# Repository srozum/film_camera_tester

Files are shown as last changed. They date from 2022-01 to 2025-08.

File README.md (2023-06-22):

# Film Camera Tester

The idea of using Arduino for measuring camera shutter timings is not new. What I've tried to do here, is to make a modular system with a set of features normally offered in professional testers, at the same time to keep its design simple and available to reproduce using off-the-shelf components.

Usually, time counting and/or light integration methods are used to test cameras. For the time counting method, you need a light sensor, a time counter, and a simple light source. With such setup you can measure exposure time(s) provided by a shutter, curtains travel speed of a focal plane shutter, flash sync contact delays, etc.
For the second method, you'll need a photosensor able to measure the amount of light and a calibrated light source. With such setup, you'll be able to measure actual exposure produced by a system "camera+lens", light meter accuracy, operation of auto-exposure cameras, etc.

This tester allows you to perform both time-based and light integration tests and calibrations of film cameras.

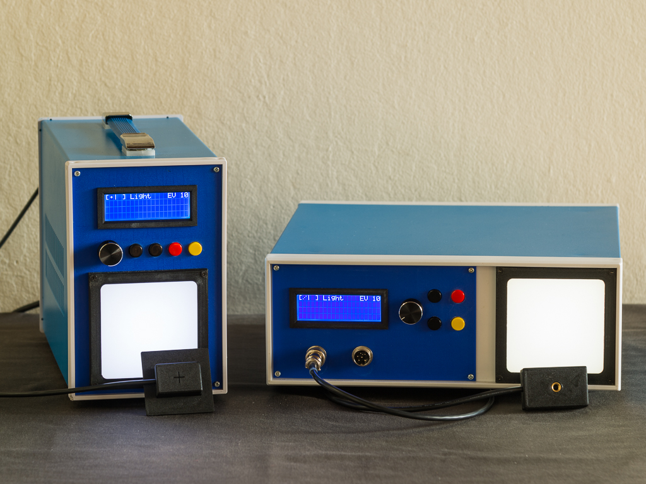
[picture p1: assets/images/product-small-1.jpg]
Film Camera Tester


### Features and characteristics

- Measures actual exposure at the film plane, which allows to test fully automatic, aperture or shutter priority cameras.
  - Accuracy ±0.05EV within 6-14EV range, although full range 5-17EV of a Light Unit can be used for testing.
  - Resolution 0.01EV
- Measures exposure time at the center of a frame of simple (leaf) and focal plane shutters of 35mm and Medium Format (6x6 or 6x45 using adapter) cameras.
  - In v2.7 only: For leaf shutters of size #00 and #0 calculates estimated effective speed according to efficiency curve.
- Measures timings of focal plane shutters with curtains traveling vertically or horizontally.
  - Results can be represented in a few different ways to help you detect different flaws in a shutter operation, such as curtains capping or tapering, uneven travel speed, etc.
  - Automatically re-calculates curtains travel time according to selected frame width or height.
- Measures delays between flash contact and shutter opening.
  - Automatically identifies X, M, or FP modes.
- Takes a series of measurements, and calculates average stats.
  - Number of tests in series can be selected in the Settings menu between 3, 5, 10, or 20.
- Allows to measure efficiency thus effective speed of a leaf shutters from size #00 and bigger.
- Automatically detects the type of connected Sensors, and notifies you if wrong sensor is connected for a specific Mode.
- Automatically detects target speed used to calculate the error.
  - Target speed can be set to "Auto" or pre-set from a list of standard speeds.
  - You also can select between two sets of standard speeds (Old style like 1/50 or New style like 1/60), depending on the type of shutter you are testing.
- Range of measured speeds from 1s to 1/8000
- Accuracy 10µs (measured in the pre-set environment, using a signal generator and specialized light source)
  - Accuracy may vary during real-life measurements with different light sources and cameras.
- Allows to check accuracy and calibrate light meters and light meters built into a cameras.
  - Light Source brightness is adjustable within 5-17EV range
  - Light Source can be switched between K12.5 and K14.03 light levels

More information on [Wiki](https://github.com/srozum/film_camera_tester/wiki).

### Buy or DIY

Since the SRT-2 Kits (assembled or not assembled), which were offered on my Tindie store, are all sold and will not be produced anymore, your only option is to make it yourself.

In '/assets' folder you can find all schematics, PCB production files, and STLs for 3D printed parts necessary to build the Tester. I recommend you carefully read Wiki pages first, explore schematics and product photos before you start ordering the parts.

### Big Thanks to

Big thanks to everyone who supported the project from the beginning.

Similar projects that helped me to start my own

 - [https://github.com/cameradactyl/Shutter-Timer](https://github.com/cameradactyl/Shutter-Timer)
 - [https://github.com/ianonahillroad/CameraShutterTimer](https://github.com/ianonahillroad/CameraShutterTimer)
 - [https://github.com/c-s-1/shutter-tester](https://github.com/c-s-1/shutter-tester)
 - [https://github.com/sokol07/LaserShutterTester](https://github.com/sokol07/LaserShutterTester)

---
This work is licensed under a [Creative Commons Attribution-ShareAlike 4.0 International License][cc-by-sa].

[][cc-by-sa]

[cc-by-sa]: http://creativecommons.org/licenses/by-sa/4.0/
[cc-by-sa-image]: https://licensebuttons.net/l/by-sa/4.0/88x31.png

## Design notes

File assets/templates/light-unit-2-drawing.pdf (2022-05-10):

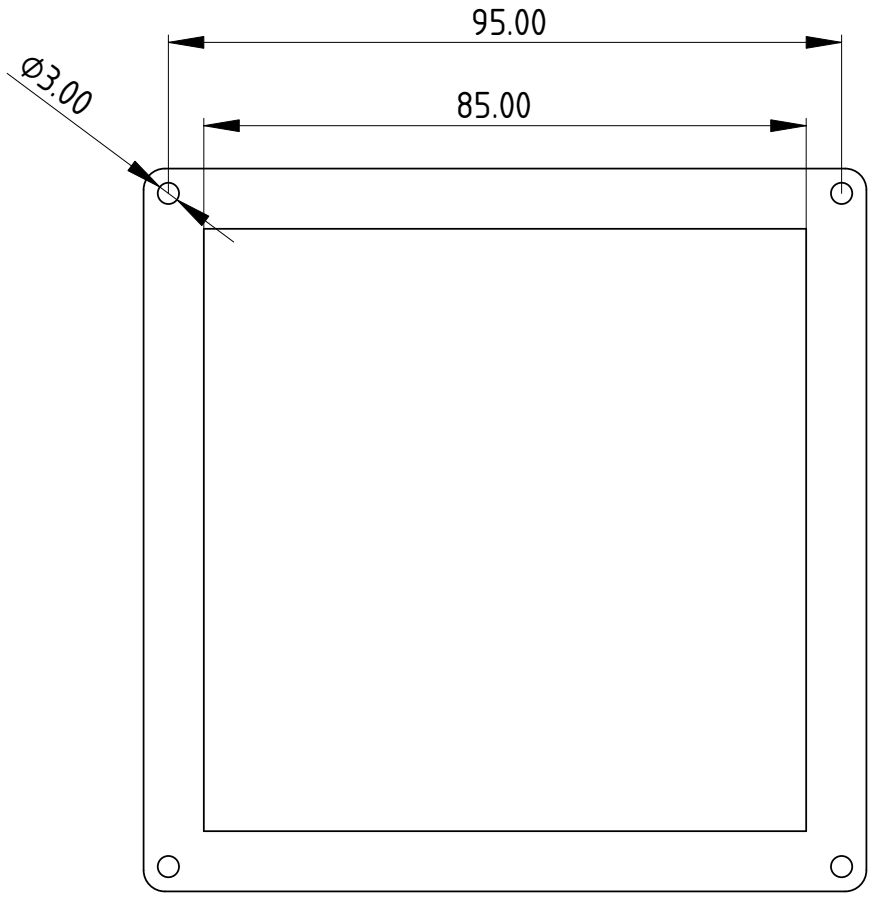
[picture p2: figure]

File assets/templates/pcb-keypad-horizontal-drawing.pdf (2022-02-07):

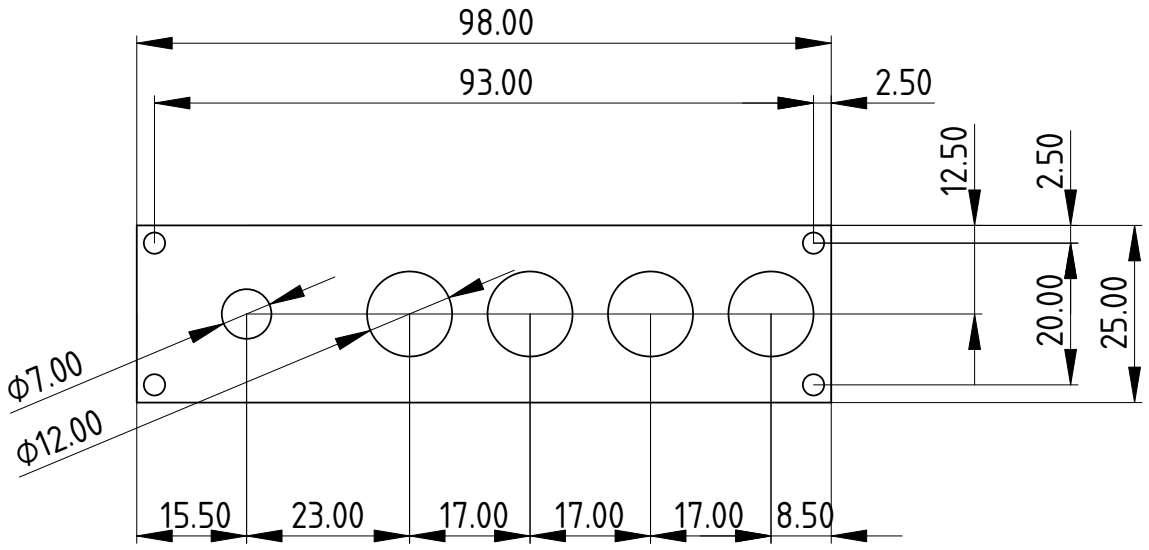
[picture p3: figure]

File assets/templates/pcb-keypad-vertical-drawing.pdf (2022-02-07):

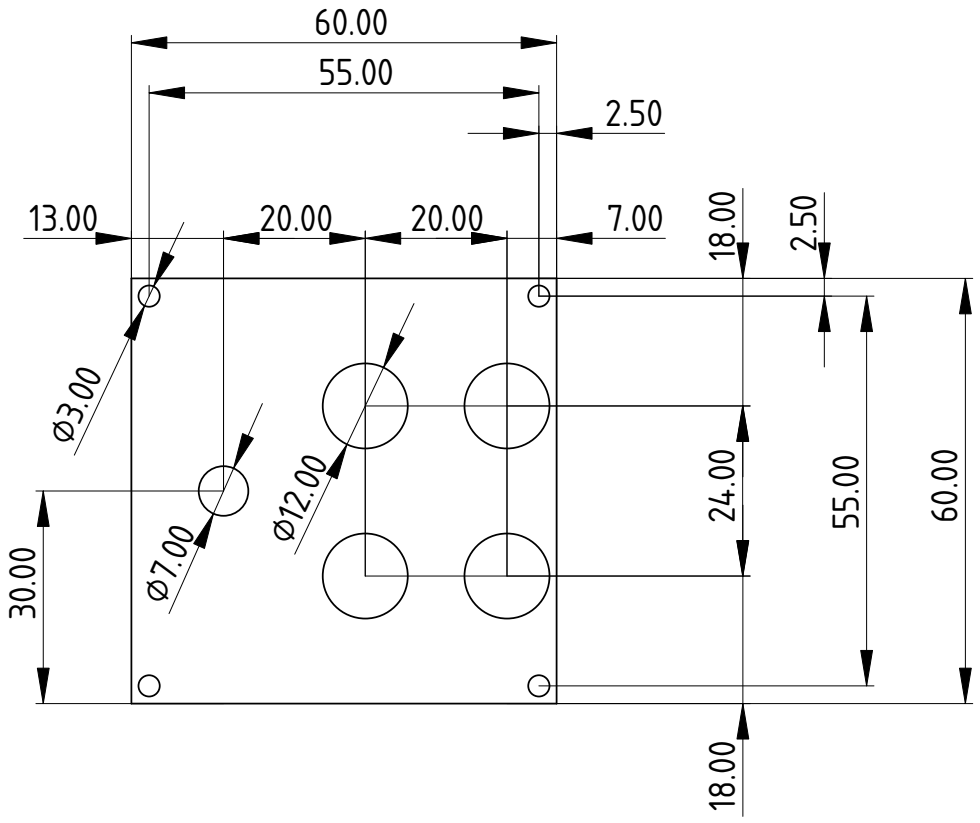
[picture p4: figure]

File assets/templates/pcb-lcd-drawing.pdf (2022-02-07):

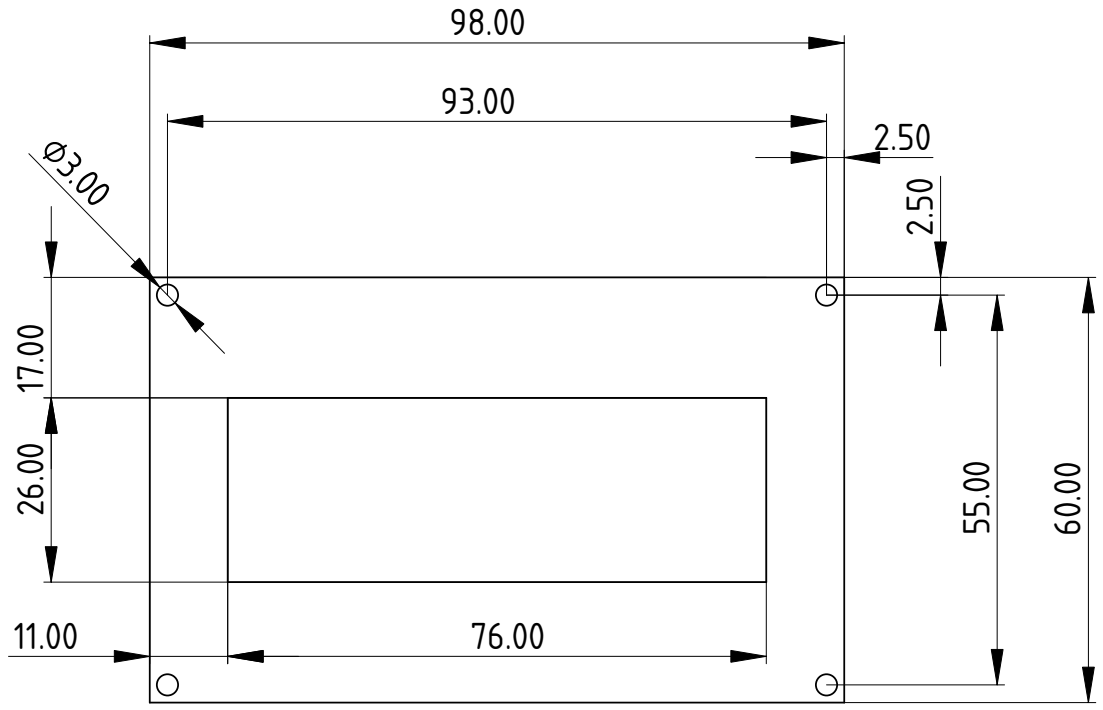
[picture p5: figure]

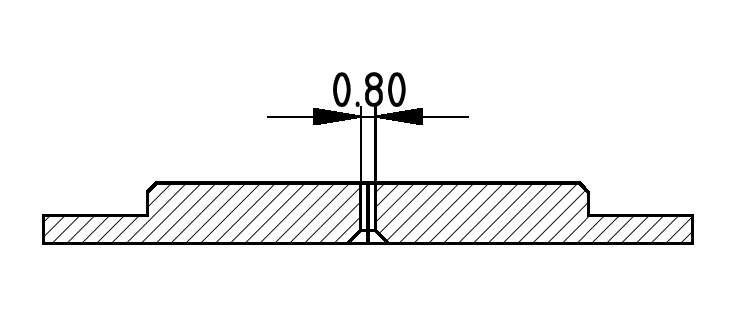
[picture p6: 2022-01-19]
assets/schematics/sensor-face-plate.png

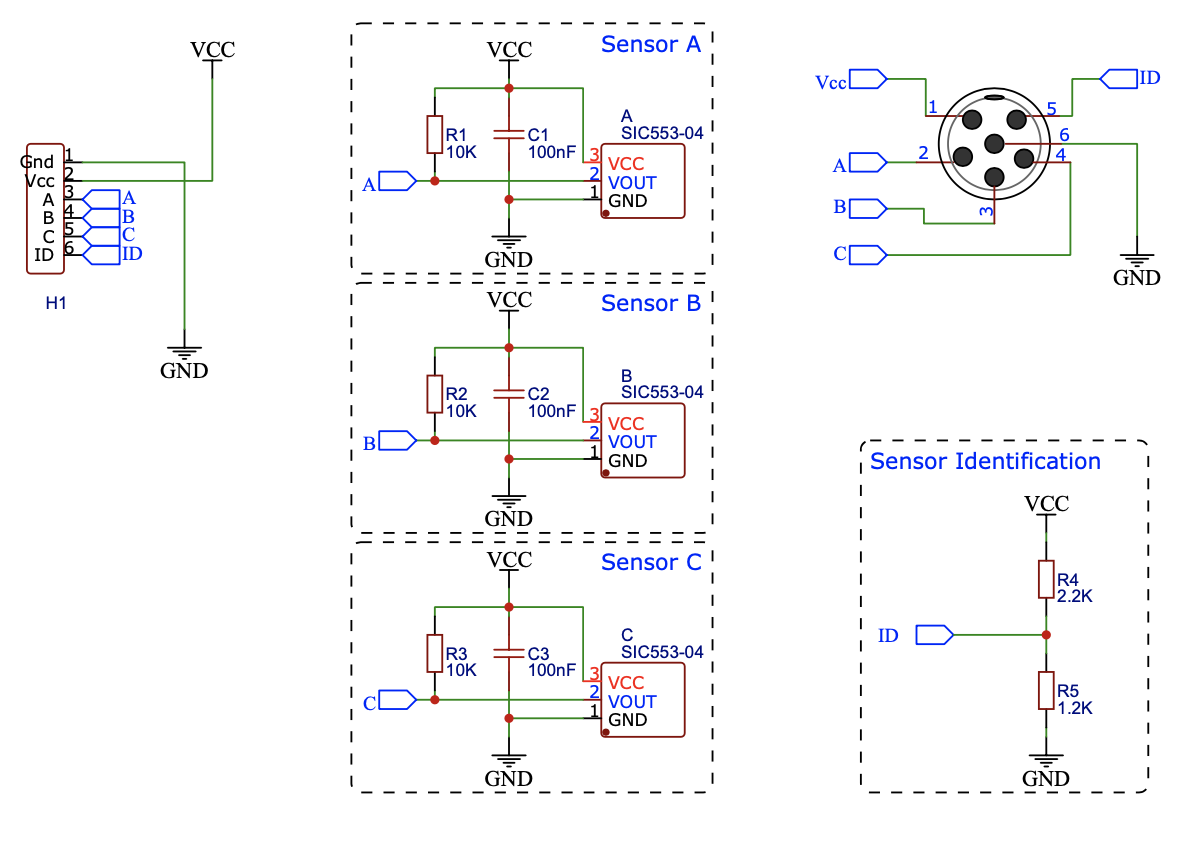
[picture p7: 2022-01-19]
assets/schematics/sensor1-v2.png

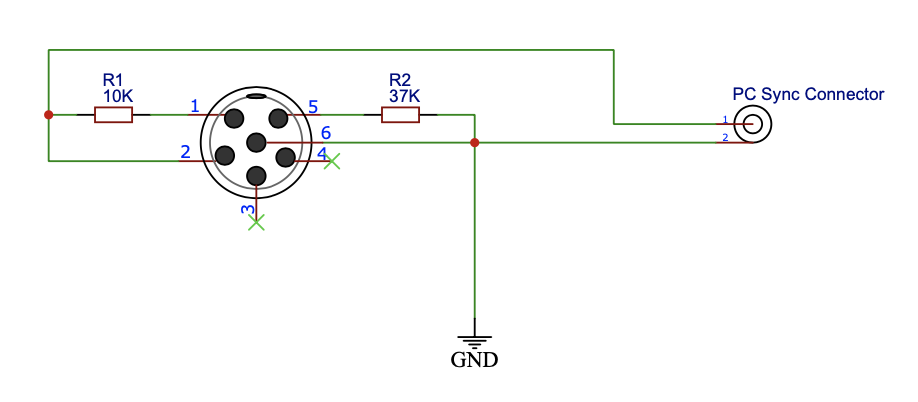
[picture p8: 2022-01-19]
assets/schematics/sensor7.png

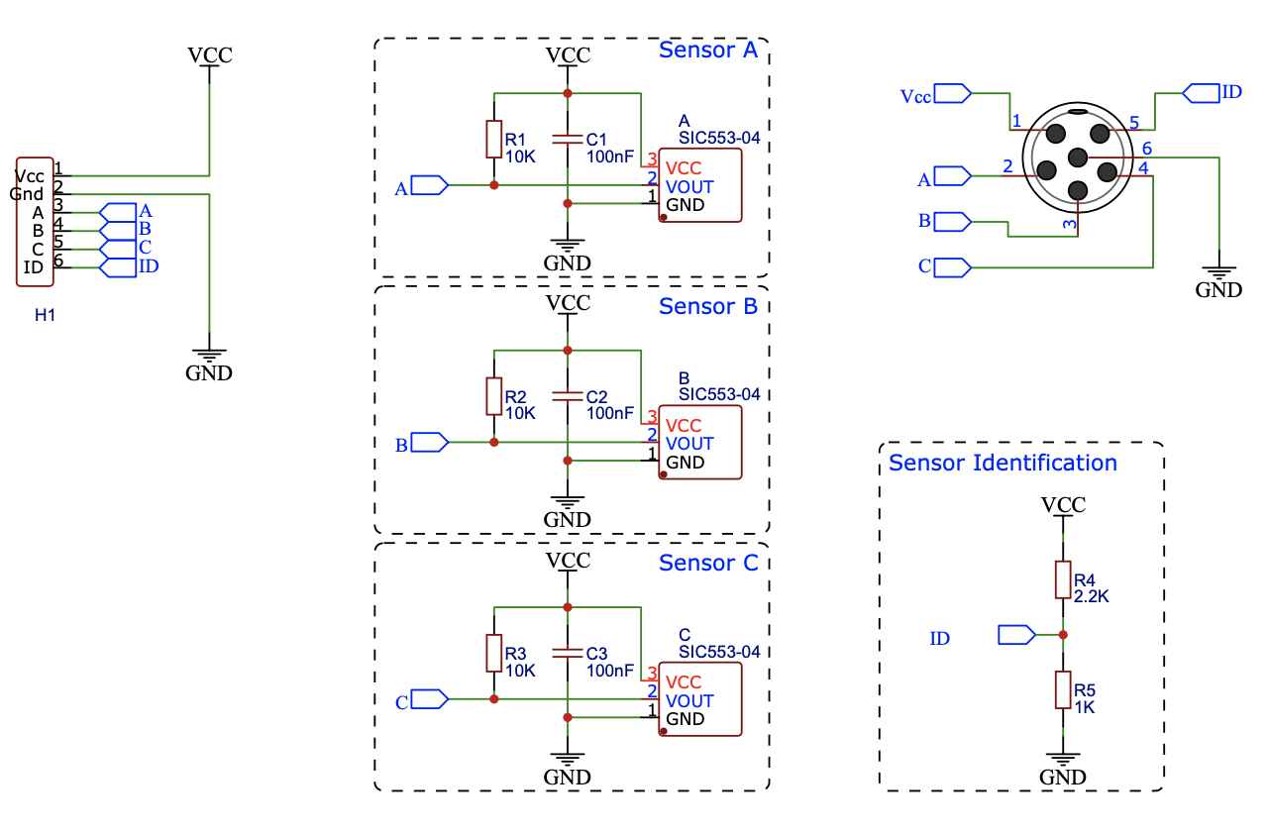
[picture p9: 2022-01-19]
assets/schematics/sensor1-v1.png

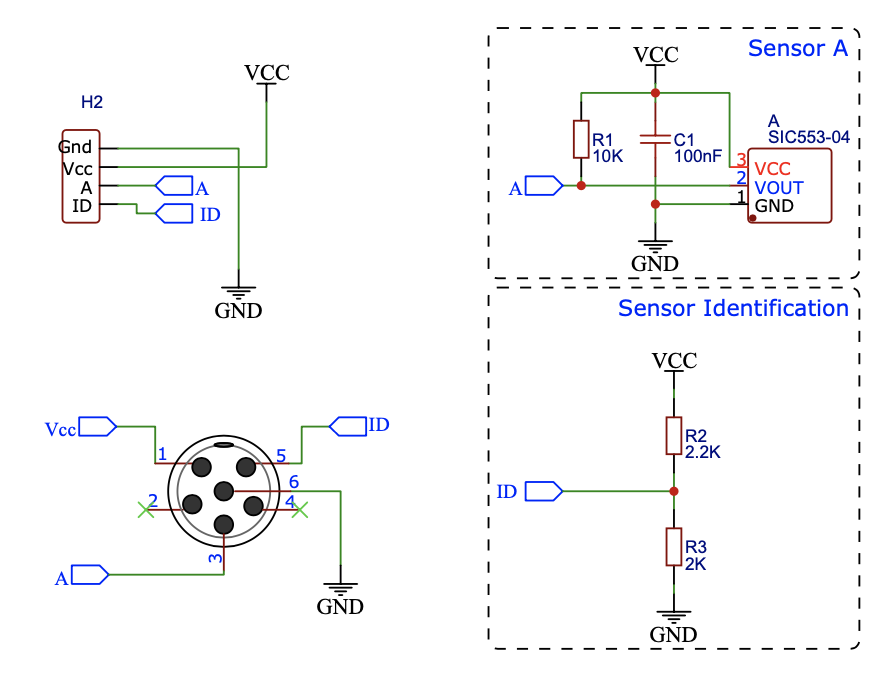
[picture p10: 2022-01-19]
assets/schematics/sensor2-v1.png

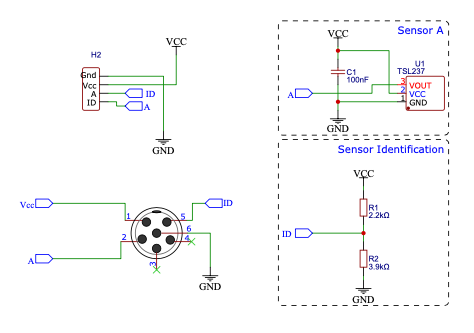
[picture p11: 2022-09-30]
assets/schematics/sensor6-v1.png

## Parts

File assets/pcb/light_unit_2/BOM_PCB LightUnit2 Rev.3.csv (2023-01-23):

ID | Name | Designator | Footprint | Quantity | Manufacturer Part | Manufacturer | Supplier | Supplier Part | Price
1 | 220uF | C1 | CAP-TH_BD10.0-P5.00-D1.0-FD | 1 | 220uF 50V 10*13 | ValuePro | LCSC | C45105 | 0.068
2 | 470uF | C2 | CAP-TH_BD10.0-P5.00-D1.0-FD | 1 | 25YXJ470MFFC10X12.5 | Rubycon | LCSC | C368591 | 0.138
3 | B2B-PH-K-S(LF)(SN) | LED,FAN | CONN-TH_B2B-PH-K-S | 2 | B2B-PH-K-S(LF)(SN) | JST | LCSC | C131337 | 0.036
4 | 2N2222A | Q1 | TO-92-3_L4.9-W3.7-P1.27-L | 1 | 2N2222 | SEMTECH | LCSC | C118536 | 0.021
5 | 1N4001-E3/73 | D1 | DO-41_BD2.4-L4.7-P8.70-D0.9-RD | 1 | 1N4001-E3/73 | VISHAY | LCSC | C145491 | 0.175
6 | HDR-M-2.54_1x6 | J1 | HDR-M-2.54_1X6 | 1 |  |  | LCSC | C190819 | 0.033
7 | LD24AJTA | U1 | LD24AJTA | 1
8 | 2K | R1 | RES-TH_BD2.2-L6.5-P10.50-D0.6 | 1 | MFR0W4F2001A50 | UniOhm | LCSC | C58593 | 0.01
9 | 2.2K | R2 | RES-TH_BD2.2-L6.5-P10.50-D0.6 | 1 | MFR0W4F2201A50 | UniOhm | LCSC | C58595 | 0.01
10 | B2B-XH-A (LF)(SN) | 12V | CONN-TH_B2B-XH-A-LF-SN | 1 | - | JST Sales America | LCSC | C158012 | 0.031
11 | 4.7K | R3,R4 | RES-TH_BD2.2-L6.5-P10.50-D0.6 | 2 | CFR0W4J0472A50 | UniOhm | LCSC | C61297 | 0.008

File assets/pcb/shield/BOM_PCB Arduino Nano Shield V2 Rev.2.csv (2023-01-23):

ID | Name | Designator | Footprint | Quantity | Manufacturer Part | Manufacturer | Supplier | Supplier Part | Price
1 | B3B-XH-A(LF)(SN) | U8 | CONN-TH_3P-P2.50_B3B-XH-A-LF-SN | 1 | B3B-XH-A(LF)(SN) | JST Sales America | LCSC | C144394 | 0.042
2 | LCD | LCD | HDR-M-2.54_1X4 | 1 |  |  | LCSC | C124378 | 0.028
3 | 24V | P1 | CONN-TH_WJ126V-5.0-2P | 1 | WJ126V-5.0-2P | ReliaPro | LCSC | C8404 | 0.065
4 | 220uF | C1,C2 | CAP-TH_BD10.0-P5.00-D1.0-FD | 2 | 220uF 50V 10*13 | ValuePro | LCSC | C45105 | 0.056
5 | Keypad | CN1 | CONN-TH_B9B-XH-A-LF-SN | 1 | - | JST Sales America | LCSC | C157966 | 0.124
6 | 10K | R1,R2 | RES-TH_BD2.5-L6.5-P10.50-D0.6 | 2 | MFR0W4F1002A50 | UniOhm | LCSC | C57436 | 0.008
7 | Light Unit | U2 | CONN-TH_6P-P2.50_B6B-XH-A-LF-SN | 1 | B6B-XH-A(LF)(SN) | JST Sales America | LCSC | C144397 | 0.072
8 | Socket A | U3 | CONN-TH_6P-P2.50_B6B-XH-A-LF-SN | 1 | B6B-XH-A(LF)(SN) | JST Sales America | LCSC | C144397 | 0.072
9 | Socket B | U4 | CONN-TH_6P-P2.50_B6B-XH-A-LF-SN | 1 | B6B-XH-A(LF)(SN) | JST Sales America | LCSC | C144397 | 0.072
10 | ArduinoNanoATmega328P | U9 | ARDUINONANO | 1
11 | active buzzer 2300Hz | BUZ1 | ACTIVE BUZZER 2300HZ | 1 | active buzzer 2300Hz

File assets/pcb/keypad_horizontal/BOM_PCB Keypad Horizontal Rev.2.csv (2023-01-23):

ID | Name | Designator | Footprint | Quantity | Manufacturer Part | Manufacturer | Supplier | Supplier Part | Price
1 | 100nF | C1,C2,C3,C4 | C0603 | 4 | CC0603KRX7R9BB104 | YAGEO | LCSC | C14663 | 0.003
2 | 10nF | C5,C6,C7 | C0603 | 3 | 0603B103K500NT | FH | LCSC | C57112 | 0.003
3 | 10K | R1,R3,R5,R6,R7,R9,R11,R12,R13,R14 | R0603 | 10 | 0603WAF1002T5E | UniOhm | LCSC | C25804 | 0.001
4 | 220 | R2,R4,R8,R10 | R0603 | 4 | 0603WAF2200T5E | UniOhm | LCSC | C22962 | 0.001

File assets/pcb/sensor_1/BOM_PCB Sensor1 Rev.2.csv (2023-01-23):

ID | Name | Designator | Footprint | Quantity | Manufacturer Part | Manufacturer | Supplier | Supplier Part | Price
1 | SIC553-04 | A,B,C | OPTO-TH_SIC553-04 | 3 | SIC553-04 | Kodenshi AUK | LCSC | C188181 | 0.566
2 | 100nF | C1,C2,C3 | C0603 | 3 | CC0603KRX7R9BB104 | YAGEO | LCSC | C14663 | 0.003
3 | 10K | R1,R2,R3 | R0603 | 3 | 0603WAF1002T5E | UniOhm | LCSC | C25804 | 0.001
4 | 2.2K | R4 | R0603 | 1 | 0603WAF2201T5E | UniOhm | LCSC | C4190 | 0.001
5 | 1.2K | R5 | R0603 | 1 | 0603WAF1201T5E | UniOhm | LCSC | C22765 | 0.001

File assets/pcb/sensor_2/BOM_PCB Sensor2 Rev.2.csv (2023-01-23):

ID | Name | Designator | Footprint | Quantity | Manufacturer Part | Manufacturer | Supplier | Supplier Part | Price
1 | SIC553-04 | A | OPTO-TH_SIC553-04 | 1 | SIC553-04 | Kodenshi AUK | LCSC | C188181 | 0.566
2 | 100nF | C1 | C0603 | 1 | CC0603KRX7R9BB104 | YAGEO | LCSC | C14663 | 0.003
3 | 10K | R1 | R0603 | 1 | 0603WAF1002T5E | UniOhm | LCSC | C25804 | 0.001
4 | 2.2K | R2 | R0603 | 1 | 0603WAF2201T5E | UniOhm | LCSC | C4190 | 0.001
5 | 2K | R3 | R0603 | 1 | 0603WAF2001T5E | UniOhm | LCSC | C22975 | 0.001

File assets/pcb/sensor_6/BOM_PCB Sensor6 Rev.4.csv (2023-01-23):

ID | Name | Designator | Footprint | Quantity | Manufacturer Part | Manufacturer | Supplier | Supplier Part | Price
1 | TSL237 | U1 | OPTO-TH_SIC553-04 | 1 | SIC553-04 | Kodenshi AUK | LCSC | C188181 | 0.106
2 | 100nF | C1 | C0805 | 1 | CL21B104KCFNNNE | SAMSUNG | LCSC | C28233 | 0.001
3 | 2.2kΩ | R1 | R0805 | 1 | 0805W8F2201T5E | UniOhm | LCSC | C17520
4 | 3.9kΩ | R2 | R0805 | 1 | 0805W8F3901T5E | UniOhm | LCSC | C17614

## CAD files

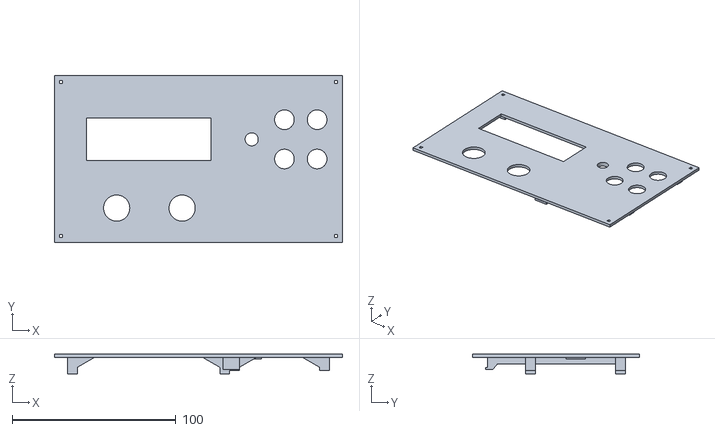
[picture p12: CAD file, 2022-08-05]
assets/stl/front-panel/horizontal_panel.stl
176.0 x 102.0 x 12.0

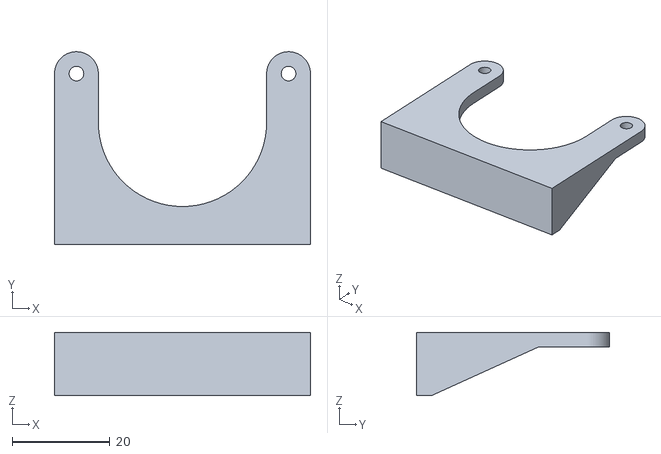
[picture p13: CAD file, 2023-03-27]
assets/stl/light-unit/support-stand.stl
52.5 x 39.5 x 13.0

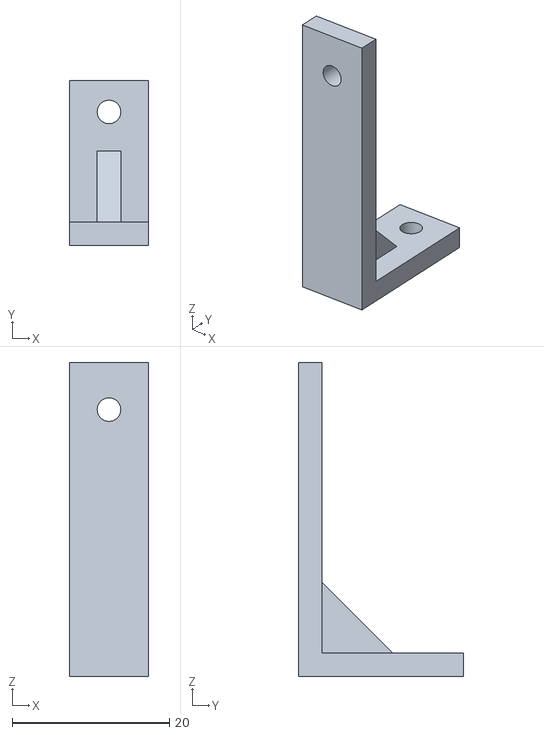
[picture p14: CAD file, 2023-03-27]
assets/stl/pcb-angle-mount.stl
10.0 x 21.0 x 40.0

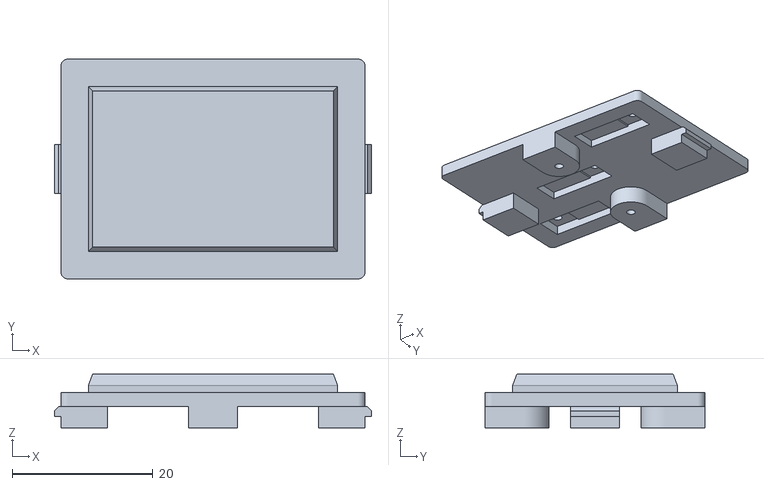
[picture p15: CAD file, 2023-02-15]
assets/stl/sensor-6/face_plate.stl
45.0 x 31.2 x 7.60

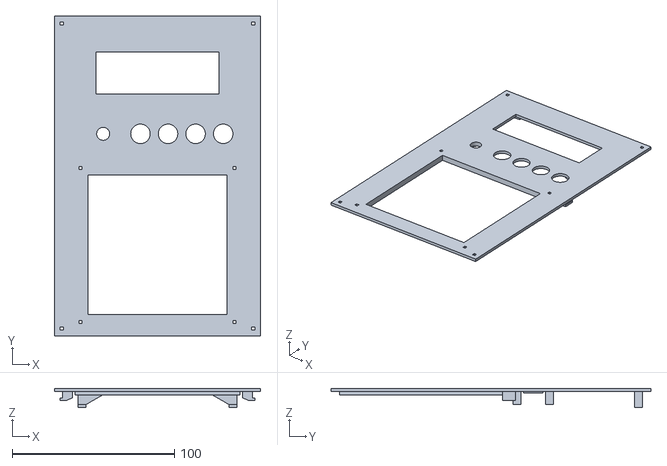
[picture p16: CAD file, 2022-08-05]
assets/stl/front-panel/vertical_panel.stl
127.0 x 197.0 x 12.0

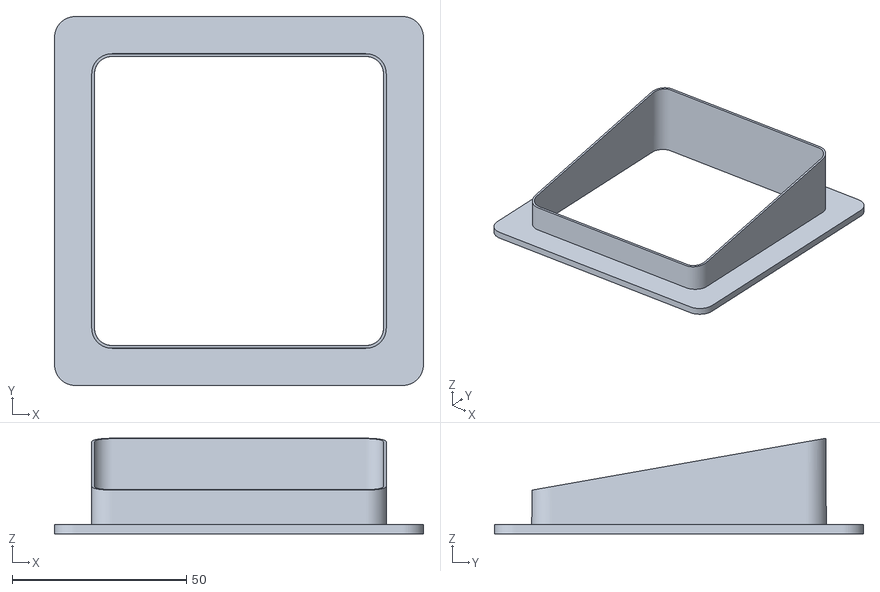
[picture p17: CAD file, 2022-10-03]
assets/stl/light-unit/flexible-hood.stl
106.0 x 106.0 x 27.5

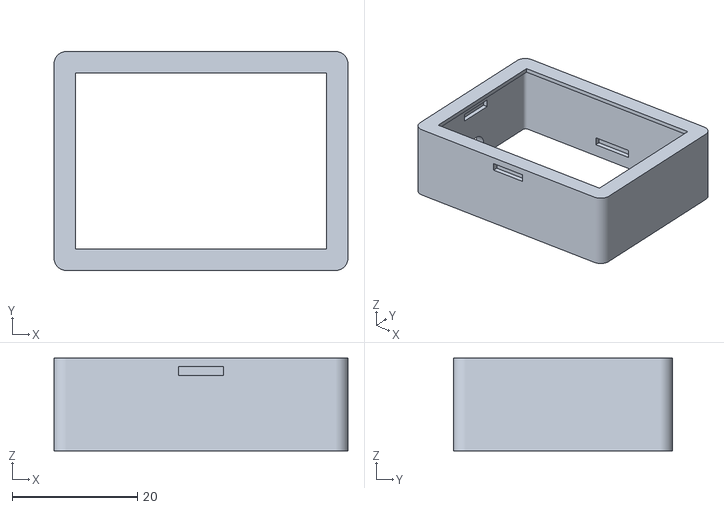
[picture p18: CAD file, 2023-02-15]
assets/stl/sensor-6/body.stl
47.0 x 35.0 x 14.8

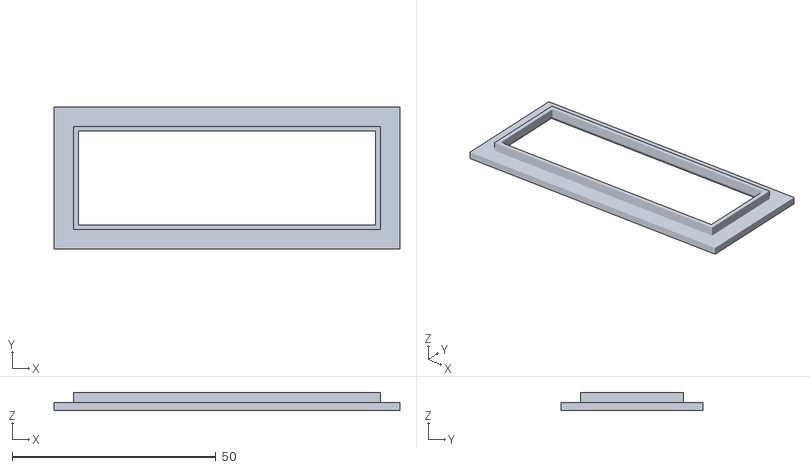
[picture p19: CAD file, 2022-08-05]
assets/stl/front-panel/lcd_besel.stl
85.0 x 35.0 x 4.50

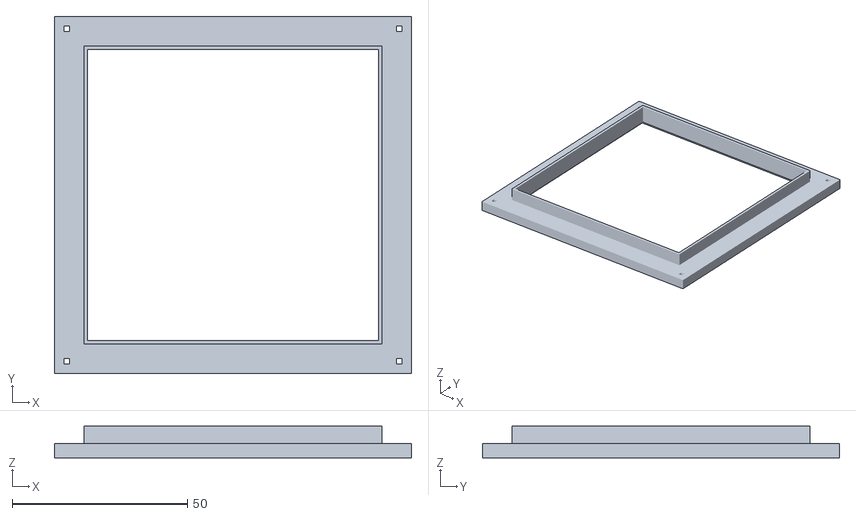
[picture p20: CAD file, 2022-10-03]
assets/stl/light-unit/reflector-mount.stl
102.0 x 102.0 x 9.00

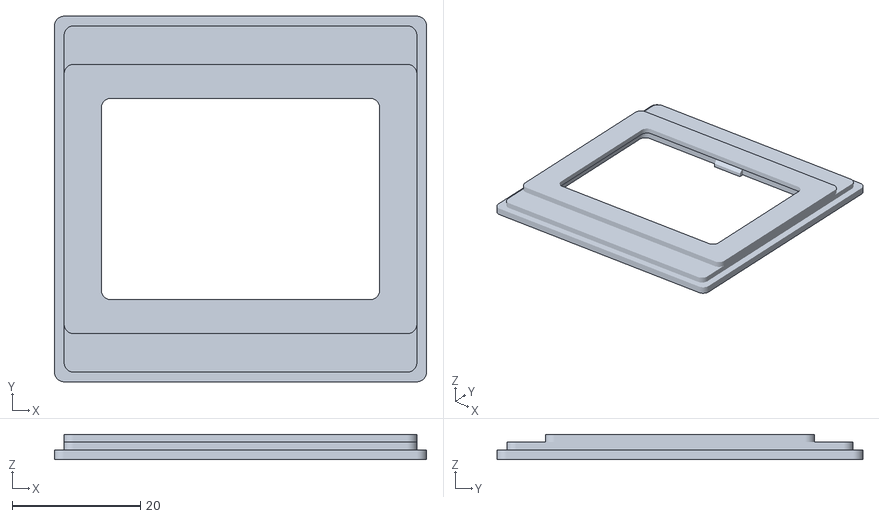
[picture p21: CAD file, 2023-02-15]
assets/stl/sensor-6/medium_format_adapter.stl
58.0 x 57.0 x 3.90

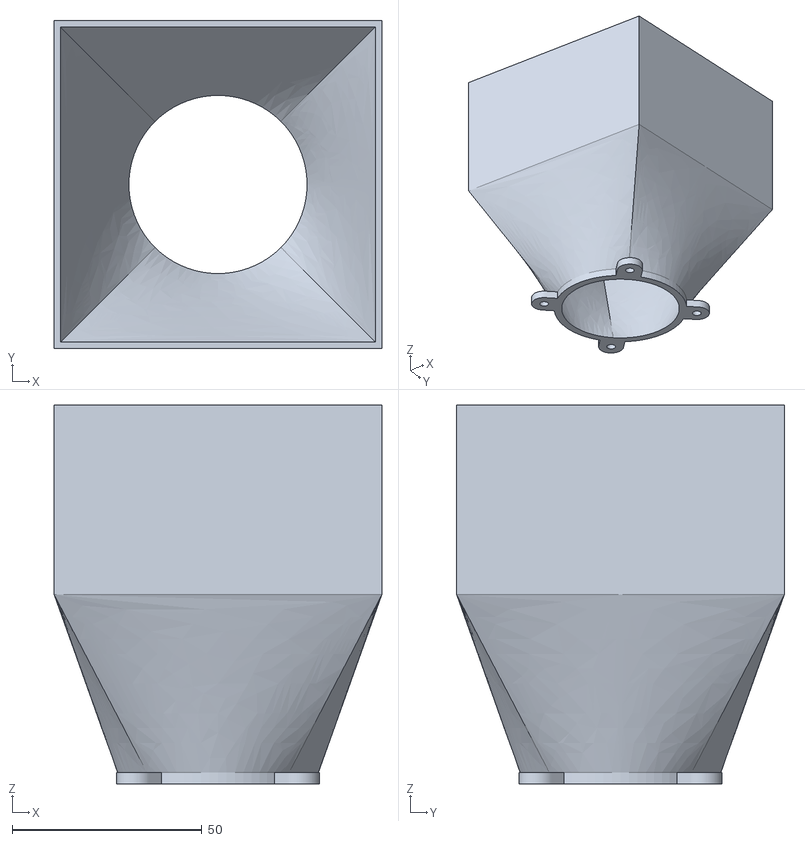
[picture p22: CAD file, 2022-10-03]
assets/stl/light-unit/reflector.stl
86.5 x 86.5 x 100.0

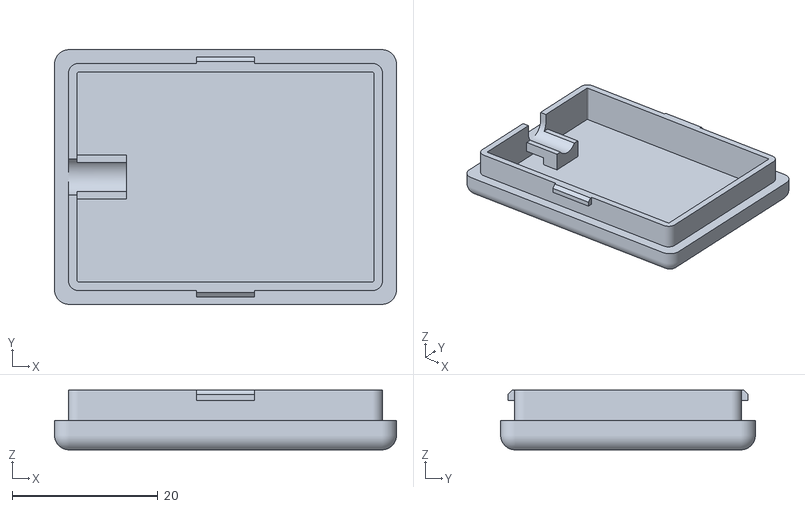
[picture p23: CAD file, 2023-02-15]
assets/stl/sensor-6/lid.stl
47.0 x 35.0 x 8.20

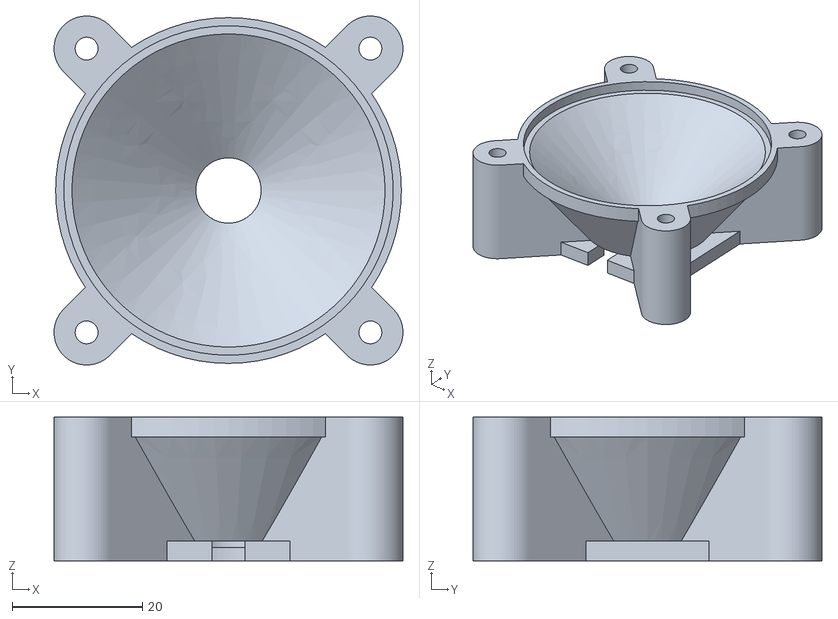
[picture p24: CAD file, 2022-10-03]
assets/stl/light-unit/led-mount.stl
53.5 x 53.5 x 22.0

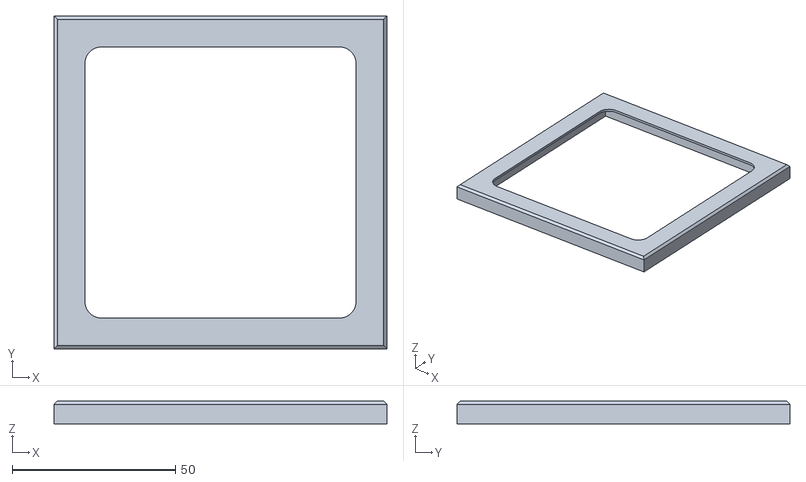
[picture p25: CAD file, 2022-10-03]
assets/stl/light-unit/face-panel.stl
102.0 x 102.0 x 7.00

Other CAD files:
assets/stl/sensor-1/body.stl
assets/stl/sensor-2/medium_format_adapter.stl
assets/stl/sensor-1/face_plate.stl
assets/stl/sensor-2/body.stl
assets/stl/sensor-1/lid.stl
assets/stl/sensor-2/lid.stl

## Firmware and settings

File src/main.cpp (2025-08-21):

/*

    Film Camera Tester
    Arduino based shield for measuring shutter speeds of film cameras,
    and testing light meters accuracy.

    Copyright (C) 2021  Serhiy Rozum

*/
#include <Arduino.h>
#include <Timer2.h>
#include <RotaryEncoder.h>
#include <Button.h>
#include <LiquidCrystal_I2C.h>

LiquidCrystal_I2C LCD(0x27, 20, 4);

#include "config.h"
#include "utills.h"
#include "glyphs.h"
#include "settings.h"
#include "active_buzzer.h"
#include "selection_items.h"
#include "exposure.h"
#include "format.h"
#include "exposure_counter.h"

ActiveBuzzer Buzzer(BUZZER_PIN);

Button ModeButton(BTN_MODE_PIN);
Button MenuButton(BTN_MENU_PIN);
Button StartButton(BTN_START_PIN);
Button StopButton(BTN_STOP_PIN);

RotaryEncoder Encoder(ENCODER_CLK_PIN, ENCODER_DA_PIN);

ISR(TIMER0_COMPB_vect)
{
  Encoder.update();
}

#define ENC_BUTTONINTERVAL 50 // check button every x milliseconds
#define ENC_HOLDTIME 2000     // report held button after 3s or so

int enc_value = 0;
unsigned long enc_last_button_check = 0;
unsigned long enc_key_down_ticks = 0;

Button EncoderButton(ENCODER_SWITCH_PIN);

Timer2 Timer;

ISR(TIMER2_OVF_vect)
{
  Timer.increment_overflow_count();
}

ExposureCounter Counter;

ISR(INT0_vect)
{
  Counter.isr();
}

ISR(TIMER2_COMPA_vect)
{
  Counter.timer();
}

#include "device.h"
#include "sensor.h"
#include "light_unit.h"

#include "socket.h"
#include "sensor_socket.h"
#include "light_unit_socket.h"

#include "items_selector.h"

#include "result.h"
#include "results/result_simple.h"
#include "results/result_focal.h"
#include "results/result_flash_sync.h"
#include "results/result_leaf_efficiency.h"
#include "results/result_light_source.h"
#include "results/result_exposure.h"

#include "mode.h"
#include "modes/mode_simple.h"
#include "modes/mode_focal.h"
#include "modes/mode_flash_simple.h"
#include "modes/mode_flash_focal.h"
#include "modes/mode_leaf_efficiency.h"
#include "modes/mode_light_source.h"
#include "modes/mode_exposure.h"

#include "mode_manager.h"
#include "settings_menu.h"

void setup()
{

  LCD.init();
  LCD.backlight();

  Utills::ShowWelcomeScreen();

  Glyphs::init();

  Buzzer.init();

  ModeButton.init();
  MenuButton.init();
  StartButton.init();
  StopButton.init();

  Encoder.init();
  Encoder.start();
  EncoderButton.init();

  // Hardware Setup
  LightUnit2.register_pins(OUTPUT, OUTPUT, NOT_IN_USE); // #2 PWM
  LightUnit2.add_ev_table(LightUnit2K12EV);             // 0 - K 12.5
  LightUnit2.add_ev_table(LightUnit2K14EV);             // 1 - K 14.03

  LightSource.register_pins(LIGHT_UNIT_PIN_1, LIGHT_UNIT_PIN_2, NOT_IN_USE);
  LightSource.register_device(&LightUnit2);
  LightSource.init();

  // Light Source Cannot be hot-swapped, so we should detect and initialize it here
  unsigned long LightSourceCheckStart = millis();
  while ((LightSourceCheckStart + 1000) > millis())
  {
    LightSource.update();
  };

  // Socket A Sensors
  Sensor1.register_pins(INPUT, INPUT, INPUT);           // #1 V1
  Sensor2.register_pins(INPUT, INPUT, INPUT);           // #1 V2
  Sensor4.register_pins(NOT_IN_USE, INPUT, NOT_IN_USE); // #2 Dot
  Sensor5.register_pins(NOT_IN_USE, INPUT, OUTPUT);     // #3 Laser

  // Socket B Sensors
  Sensor6.register_pins(INPUT, NOT_IN_USE, NOT_IN_USE); // #6 Exposure
  Sensor7.register_pins(INPUT, NOT_IN_USE, NOT_IN_USE); // #7 Flash

  SocketA.register_pins(SOCKET_A_SENSOR_PIN_1, SOCKET_A_SENSOR_PIN_2, SOCKET_A_SENSOR_PIN_3);
  SocketA.register_device(&Sensor1);
  SocketA.register_device(&Sensor2);
  SocketA.register_device(&Sensor4);
  SocketA.register_device(&Sensor5);
  SocketA.init();

  SocketB.register_pins(SOCKET_B_SENSOR_PIN_1, NOT_IN_USE, NOT_IN_USE);
  SocketB.register_device(&Sensor6);
  SocketB.register_device(&Sensor7);
  SocketB.init();

  ModeMgr.init();

  delay(1000);
  LCD.clear();
}

void loop()
{
  // Check Sockets status
  SocketA.update();
  SocketB.update();

  if (ModeMgr.is_runing())
  {
    if (ModeMgr.is_ready())
    {
      ModeMgr.run();
    }
    else
    {
      ModeMgr.stop();
    }
    LCD.clear();
  }
  else
  {

    // Mode Parameter Selector if present

    enc_value = Encoder.getValue();

    if (enc_value < 0)
    {
      ModeMgr.selector_next();
    }
    else if (enc_value > 0)
    {
      ModeMgr.selector_prev();
    }

    // Mode Selection Menu
    if (ModeButton.pressed())
    {
      ModeMgr.select();
      LCD.clear();
    }

    // Settings Menu
    if (MenuButton.pressed())
    {
      Menu.select();
      ModeMgr.reload();
      LCD.clear();
    }

    // Start Measurement
    if (StartButton.pressed())
    {
      ModeMgr.start();
      LCD.clear();
    }

    // Calibration on Encoder button held for 3 sec
    if (EncoderButton.pressed())
    {

      if ((millis() - enc_last_button_check) > ENC_BUTTONINTERVAL)
      {
        enc_last_button_check = millis();

        enc_key_down_ticks++;

        if (enc_key_down_ticks > (ENC_HOLDTIME / ENC_BUTTONINTERVAL))
        {
          enc_key_down_ticks = 0;
          ModeMgr.calibrate();
          LCD.clear();
        }
      }
      else
      {
        enc_key_down_ticks = 0;
      }
    }

  }

  ModeMgr.update(); // Print
}

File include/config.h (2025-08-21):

/*
    Film Camera Tester
    Copyright (C) 2021  Serhiy Rozum
*/

#pragma once

#ifndef _CONFIG_H
#define _CONFIG_H

// Constants

#define SRT_VERSION_MAJOR 2
#define SRT_VERSION_MINOR 9

#define NOT_IN_USE 255

#define MENU_SIZE 4

#define ENCODER_DELAY 100

const char ModeSimpleName[] PROGMEM = "Simple Shutters";
const char ModeFocalVerticalName[] PROGMEM = "Focal Vertical";
const char ModeFocalHorizontalName[] PROGMEM = "Focal Horizontal";
const char ModeLightSourceName[] PROGMEM = "Light Source";
const char ModeExposureName[] PROGMEM = "Exposure Error";
const char ModeSeriesSimpleName[] PROGMEM = "Series Average";
const char ModeFlashSimpleName[] PROGMEM = "Flash Sync Simple";
const char ModeFlashFocalName[] PROGMEM = "Flash Sync Focal";
const char ModeLeafEfficiencyName[] PROGMEM = "Leaf Efficiency";

const char ShortNameSimple[] PROGMEM = "Simple";
const char ShortNameFocalVertical[] PROGMEM = "FP Vert";
const char ShortNameFocalHorizontal[] PROGMEM = "FP Horiz";
const char ShortNameLight[] PROGMEM = "Light";
const char ShortExposure[] PROGMEM = "Exposure";
const char ShortNameSeries[] PROGMEM = "Average";
const char ShortNameFlashSimple[] PROGMEM = "Flash Simple";
const char ShortNameFlashFocal[] PROGMEM = "Flash Focal";
const char ShortNameLeafEff[] PROGMEM = "Leaf Eff";

// Pins map of SRT version 2
// Based on Arduino Nano

#define BUZZER_PIN 13

#define BTN_MODE_PIN A0 // Mode button
#define BTN_MENU_PIN A1 // Menu button
#define BTN_START_PIN 7 // Start button
#define BTN_STOP_PIN 6  // Stop button, have to be on same register as Socket A

#define ENCODER_CLK_PIN 12
#define ENCODER_DA_PIN 11
#define ENCODER_SWITCH_PIN 8

// Socket A
#define SOCKET_A_ID_PIN A6 // Have to be any analog pin
#define SOCKET_A_SENSOR_PIN_1 3
#define SOCKET_A_SENSOR_PIN_2 4
#define SOCKET_A_SENSOR_PIN_3 5

// Socket B
#define SOCKET_B_ID_PIN A7 // Have to be any analog pin
#define SOCKET_B_SENSOR_PIN_1 2

// Light Unit Socket
#define LIGHT_UNIT_ID_PIN A2 // Have to be any analog pin
#define LIGHT_UNIT_PIN_1 9   // Light PWM
#define LIGHT_UNIT_PIN_2 10  // Fan

#endif

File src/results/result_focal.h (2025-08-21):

/*

    Focal Plane Shutter Result
    - times at three points of frame A/B/C
    - speed at the center
    - target speed (set or automatically detected)
    - EV error compared to target speed
    - curtains travel time To/Tc

    Copyright (C) 2021  Serhiy Rozum

*/
#pragma once

#ifndef _RESULT_FOCAL_H
#define _RESULT_FOCAL_H

#define EDGES_CORRECTION (12.25)
#define OVERLAP_COMPENSATION (0.17)
#define OPENING_CURTAIN_CORRECTION (29.0)
#define CLOSING_CURTAIN_CORRECTION (-17.0)

class ResultFocal : public Result
{

public:

  ResultFocal(uint8_t num_of_tests) : Result(num_of_tests) {
    // To
    stats[num_of_stats] = new Stats();
    num_of_stats++;
    // Tc
    stats[num_of_stats] = new Stats();
    num_of_stats++;
  };

  void add_test()
  {
    if (selected_item.value == 3)
    {

      float Toc = measurements[3]->time() * frame_ratio();
      stats[0]->add_test(num_of_tests, tests_taken, Toc);

      float Tcc = measurements[4]->time() * frame_ratio();
      stats[1]->add_test(num_of_tests, tests_taken, Tcc);

    }
    Result::add_test();
  };

  void print()
  {
    if (finished())
    {
      if (measurements[1]->time() > RESULT_MAX_MEASURED_TIME)
      {
        print_error();
      }
      else
      {
        switch (selected_item.value)
        {
        case 0: // Time mode
          print_focal_time();
          break;
        case 1: // Exposure mode
          print_focal_exposure();
          break;
        case 2: // Curtains travel time mode
          print_focal_curtains_ab();
          break;
        case 3: // Average curtains travel time
          print_focal_average();
          break;
        }
      }
    }
    else if (tests_taken > 0)
    {
      if (measurements[1]->time() > RESULT_MAX_MEASURED_TIME)
      {
        print_error();
      }
      else
      {
        print_focal_curtains();
        print_tests_counter();
      }
    }
    else
    {
      print_running();
    }
  }

  void print_focal_time()
  {

    float Toc = measurements[3]->time() * frame_ratio();
    float Tcc = measurements[4]->time() * frame_ratio();

    float Ts = ((Toc + Tcc) * OVERLAP_COMPENSATION) / (2.0 * frame_space);

    float Ta = measurements[0]->time() + EDGES_CORRECTION + Ts;
    float Tb = measurements[1]->time();
    float Tc = measurements[2]->time() + EDGES_CORRECTION + Ts;

    char buff[20];
    char buff_a[8];
    char buff_b[8];

    Format::time(Ta, buff_a);
    Format::speed(Tb, buff_b);

    sprintf_P(buff, PSTR("A %7s S: %-5s "), buff_a, buff_b);
    LCD.setCursor(0, 1);
    LCD.print(buff);

    Format::time(Tb, buff_a);
    Format::time(Toc, buff_b);

    sprintf_P(buff, PSTR("B %7s To %-7s"), buff_a, buff_b);
    LCD.setCursor(0, 2);
    LCD.print(buff);

    Format::time(Tc, buff_a);
    Format::time(Tcc, buff_b);

    sprintf_P(buff, PSTR("C %7s Tc %-7s"), buff_a, buff_b);
    LCD.setCursor(0, 3);
    LCD.print(buff);
  }

  void print_focal_exposure()
  {
    float Ts = ((measurements[3]->time() + measurements[4]->time()) * OVERLAP_COMPENSATION) / (2.0 * frame_space);

    float Ta = measurements[0]->time() + EDGES_CORRECTION + Ts;
    float Tb = measurements[1]->time();
    float Tc = measurements[2]->time() + EDGES_CORRECTION + Ts;

    LongSelectionItem target_speed = Exposure::nearest_speed(Tb);

    float ev_error;

    char buff[20];
    char buff_a[8];
    char buff_b[8];

    ev_error = Exposure::ev_error(Ta, Tb);
    Format::ev_error(ev_error, buff_a, 2);
    Format::speed(Tb, buff_b);

    sprintf_P(buff, PSTR("A %7s S: %-5s "), buff_a, buff_b);
    LCD.setCursor(0, 1);
    LCD.print(buff);

    Format::time(Tb, buff_a);
    ev_error = Exposure::ev_error(Tb, target_speed.value);
    Format::ev_error(ev_error, buff_b);

    sprintf_P(buff, PSTR("B %7s Er %-7s"), buff_a, buff_b);
    LCD.setCursor(0, 2);
    LCD.print(buff);

    ev_error = Exposure::ev_error(Tc, Tb);
    Format::ev_error(ev_error, buff_a, 2);

    sprintf_P(buff, PSTR("C %7s of %-5s "), buff_a, target_speed.label);
    LCD.setCursor(0, 3);
    LCD.print(buff);
  }

  void print_focal_curtains_ab()
  {
    char buff[20];
    char buff_a[8];
    char buff_b[8];

    float Toc = measurements[3]->time() * frame_ratio();
    float Tcc = measurements[4]->time() * frame_ratio();

    float Toa = (Exposure::time(measurements[0]->start, measurements[1]->start) + OPENING_CURTAIN_CORRECTION) * frame_ratio();
    float Tca = (Exposure::time(measurements[0]->stop, measurements[1]->stop) + CLOSING_CURTAIN_CORRECTION) * frame_ratio();

    Format::time(Toa, buff_a);
    Format::time(Tca, buff_b);

    sprintf_P(buff, PSTR("AB %7s   %7s"), buff_a, buff_b);
    LCD.setCursor(0, 1);
    LCD.print(buff);

    float Tob = (Exposure::time(measurements[1]->start, measurements[2]->start) + OPENING_CURTAIN_CORRECTION) * frame_ratio();
    float Tcb = (Exposure::time(measurements[1]->stop, measurements[2]->stop) + CLOSING_CURTAIN_CORRECTION) * frame_ratio();


    Format::time(Tob, buff_a);
    Format::time(Tcb, buff_b);

    sprintf_P(buff, PSTR("BC %7s   %7s"), buff_a, buff_b);
    LCD.setCursor(0, 2);
    LCD.print(buff);

    Format::time(Toc, buff_a);
    Format::time(Tcc, buff_b);

    sprintf_P(buff, PSTR("To %7s Tc%7s"), buff_a, buff_b);
    LCD.setCursor(0, 3);
    LCD.print(buff);
  }

  // Intermediate result for curtains average time
  void print_focal_curtains()
  {
    char buff[21];
    char buff_a[8];
    char buff_b[8];

    float Toc = measurements[3]->time() * frame_ratio();
    Format::time(Toc, buff_a);

    float Tcc = measurements[4]->time() * frame_ratio();
    Format::time(Tcc, buff_b);

    sprintf_P(buff, PSTR("To %7s Tc%7s"), buff_a, buff_b);
    LCD.setCursor(0, 1);
    LCD.print(buff);
  }

  void print_focal_average()
  {
    char buff[20];
    char buff_a[8];
    char buff_b[8];

    Format::time(stats[0]->min, buff_a);
    Format::time(stats[1]->min, buff_b);

    sprintf_P(buff, PSTR("Mn %7s   %7s"), buff_a, buff_b);
    LCD.setCursor(0, 1);
    LCD.print(buff);

    Format::time(stats[0]->avg, buff_a);
    Format::time(stats[1]->avg, buff_b);

    sprintf_P(buff, PSTR("Av %7s   %7s"), buff_a, buff_b);
    LCD.setCursor(0, 2);
    LCD.print(buff);

    Format::time(stats[0]->max, buff_a);
    Format::time(stats[1]->max, buff_b);

    sprintf_P(buff, PSTR("Mx %7s   %7s"), buff_a, buff_b);
    LCD.setCursor(0, 3);
    LCD.print(buff);
  }

  float frame_ratio()
  {
    return frame_space / sensor_space;
  }

};

#endif

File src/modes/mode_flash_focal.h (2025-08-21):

/*

    Mode Focal Base

    Copyright (C) 2021  Serhiy Rozum

*/
#pragma once

#ifndef _MODE_FLASH_FOCAL_H
#define _MODE_FLASH_FOCAL_H

class ModeFlashFocal : public Mode
{

public:
  template <byte N>
  ModeFlashFocal(Requirement (&requirements)[N], LightUnitSocket *light_source_socket, SensorSocket *socket_a, SensorSocket *socket_b) : Mode(requirements, light_source_socket, socket_a, socket_b)
  {
    result = new ResultFlashSync(1);
  };

  void take_measurement()
  {

    // A - top right sensor
    byte sensor_a_mask = sockets[0]->PinToBitMask(0);
    // B - center censor
    byte sensor_b_mask = sockets[0]->PinToBitMask(1);
    // C - bottom left sensor
    byte sensor_c_mask = sockets[0]->PinToBitMask(2);
    // Flash sync sensor on Socket B, but on the same port
    byte flash_sensor_mask = sockets[1]->PinToBitMask(0);

    byte sensor_port = sockets[0]->PinToPort(1);


    byte fired_flash = 1;
    byte fired_a = 2;
    byte fired_b = 2;
    byte fired_c = 2;
    byte measure = 4;

    Timer2::Count flash;
    Timer2::Count start_a;
    Timer2::Count stop_a;
    Timer2::Count start_b;
    Timer2::Count stop_b;
    Timer2::Count start_c;
    Timer2::Count stop_c;

    do
    {
      //  read Flash Sync Sensor
      if (!(*portInputRegister(sensor_port) & flash_sensor_mask) && (fired_flash == 1))
      {
        Timer.get_count(&flash);
        fired_flash--;
        measure--;
      }

      //  read Sensor A
      if (!(*portInputRegister(sensor_port) & sensor_a_mask) && (fired_a == 2))
      {
        Timer.get_count(&start_a);
        fired_a--;
      }
      if ((*portInputRegister(sensor_port) & sensor_a_mask) && (fired_a == 1))
      {
        Timer.get_count(&stop_a);
        fired_a--;
        measure--;
      }

      //  read Sensor B
      if (!(*portInputRegister(sensor_port) & sensor_b_mask) && (fired_b == 2))
      {
        Timer.get_count(&start_b);
        fired_b--;
      }
      if ((*portInputRegister(sensor_port) & sensor_b_mask) && (fired_b == 1))
      {
        Timer.get_count(&stop_b);
        fired_b--;
        measure--;
      }

      //  read Sensor C
      if (!(*portInputRegister(sensor_port) & sensor_c_mask) && (fired_c == 2))
      {
        Timer.get_count(&start_c);
        fired_c--;
      }
      if ((*portInputRegister(sensor_port) & sensor_c_mask) && (fired_c == 1))
      {
        Timer.get_count(&stop_c);
        fired_c--;
        measure--;
      }

      if (StopButton.pressed() == true)
      {
        measure = 0;
        stop();
      }
    } while (measure > 0);

    if ((measure == 0) && (running == true))
    {
      if (start_a.total_count() < start_c.total_count())
      {
        // A->C (Up-to-Down shutter or Right-to-Left)
        result->add_measurement(start_b.total_count(), stop_b.total_count());
        // +X
        result->add_measurement(start_c.total_count(), flash.total_count());
        // X-D
        result->add_measurement(flash.total_count(), stop_a.total_count());
        // -X (FP)
        result->add_measurement(flash.total_count(), start_a.total_count());
      }
      else
      {
        // C->A (Down-to-Up shutter OR Sensor is upside down (Left-to-Right doesn't exists))
        result->add_measurement(start_b.total_count(), stop_b.total_count());
        // +X
        result->add_measurement(start_a.total_count(), flash.total_count());
        // X-D
        result->add_measurement(flash.total_count(), stop_c.total_count());
        // -X (FP)
        result->add_measurement(flash.total_count(), start_c.total_count());
      }
      result->add_test();
    }
  }
};

#endif

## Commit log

2022-01-14 Initial commit - demo code for kit board
2022-02-07 pcb templates for front panel cutouts
2022-04-14 Added schematics of Sensor #3
2022-08-05 STL files for sensors and fron panels
    [body.stl, face_plate.stl, horizontal_panel.stl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]
2022-10-03 Enclosure and Light Unit materials
    [face-panel.stl, flexible-hood.stl, led-mount.stl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]
2023-01-23 Datasheets and PCB production files added
    [BOM_PCB Arduino Nano Shield V2 Rev.2.csv, BOM_PCB Keypad Horizontal Rev.2.csv, BOM_PCB Keypad Vertical Rev.1.csv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]
2023-02-15 firmware update
    [body.stl, face_plate.stl, lid.stl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]
2023-03-02 beer button
2023-03-27 STLs for support parts
    [pcb-angle-mount.stl, support-stand.stl]

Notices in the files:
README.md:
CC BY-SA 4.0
